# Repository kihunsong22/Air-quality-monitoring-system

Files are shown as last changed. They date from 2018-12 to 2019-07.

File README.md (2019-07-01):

# Air-quality-monitoring-system
Air quality monitoring system based on LoRa and Node.JS

<!-- ![LoRa_modules](Pictures/V2_sensor.jpg | width=400) -->
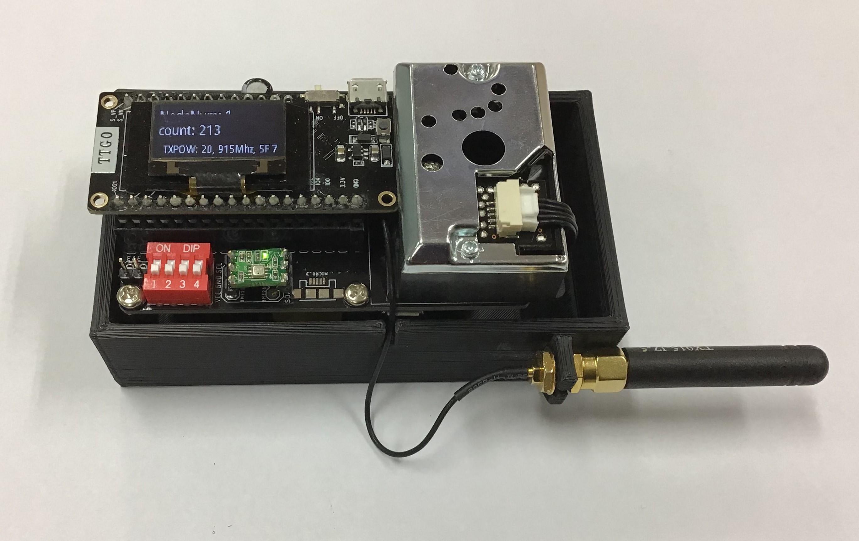
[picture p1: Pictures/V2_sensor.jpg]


LoRa Sensor Node

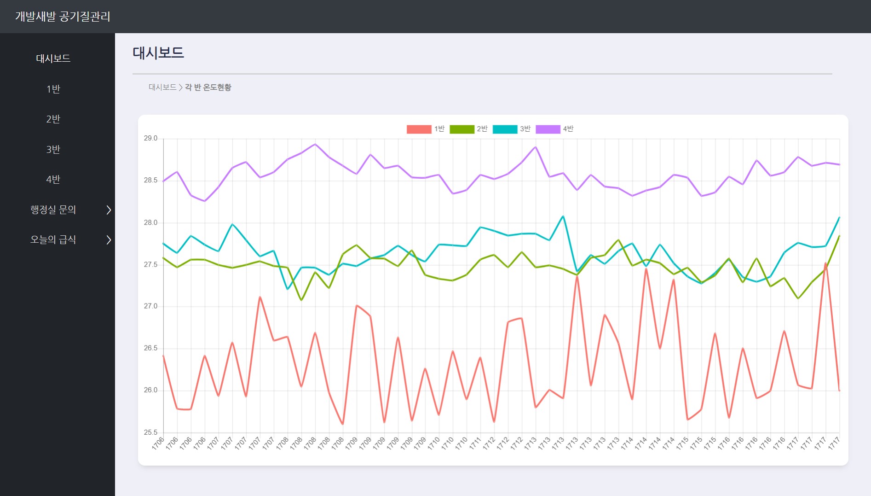
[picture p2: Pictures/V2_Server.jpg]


Node.JS Web Server

Hardware is based on TTGO-LoRa V2 board. Sensor nodes utilize BME280 and GP2y1024AU0F sensor and send it to the gateway via LoRa. Gateway will then upload the sensor data to the server via WiFi.

My system uses 4 sensor nodes and 1 gateway, but configurations can be changed

### Issues & To-Do lists
1. CLX1 pin on the ESP32 which is connected to pin 0 of the DIP switch maintains 2.7V, and prevents uploading when pulled up to 3.3V. Pin 2 of ESP32 should be changed to pin 0 of ESP32 since it's connected to the board LED
1. The PCB isn't long enough for the GP2Y10 dust sensor. And the 18650 battery blocks the hole for the sensor
1. 3.3V -> 5V boost converter is necessary since the GP2Y10 sensor utilizes 5V.
1. 3.3V and GND test pins should be moved to a different location

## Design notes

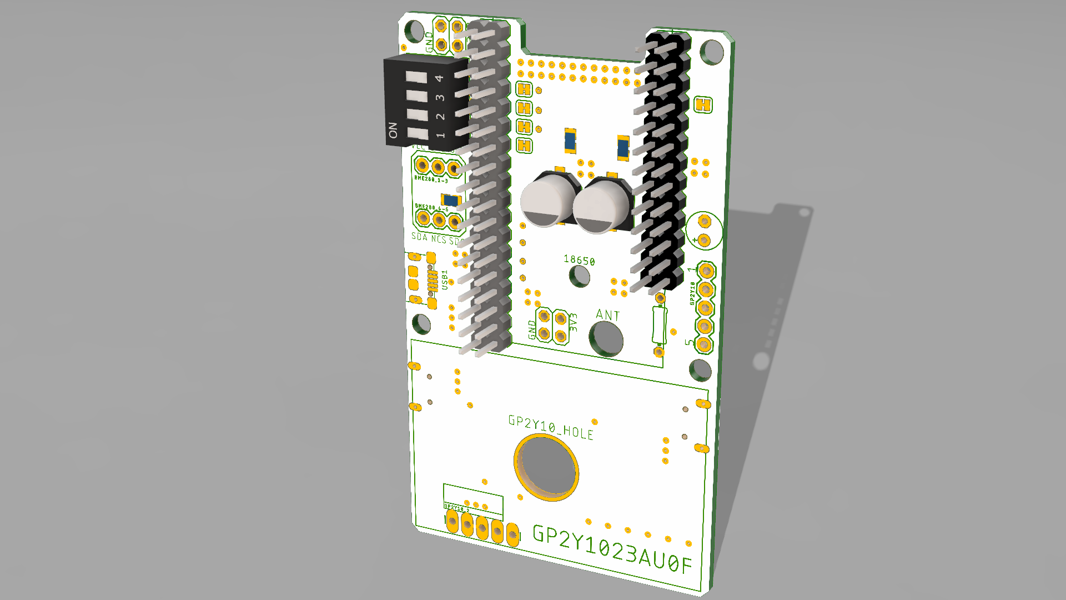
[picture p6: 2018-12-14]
V2/Pictures/PCB/PCB Rendering.png

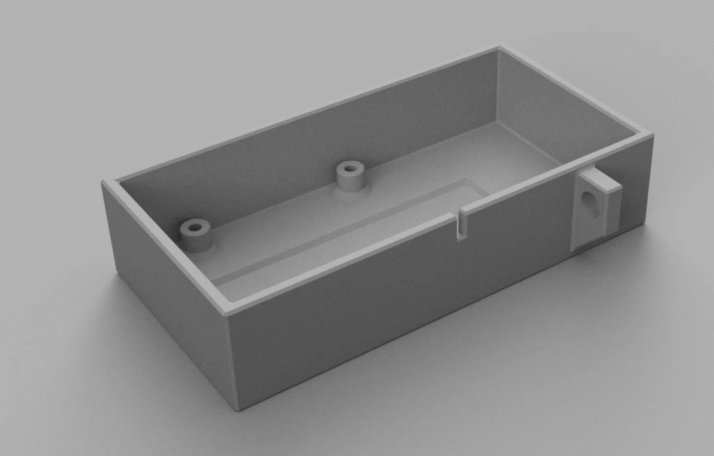
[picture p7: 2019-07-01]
Pictures/LoRa case rendering.png

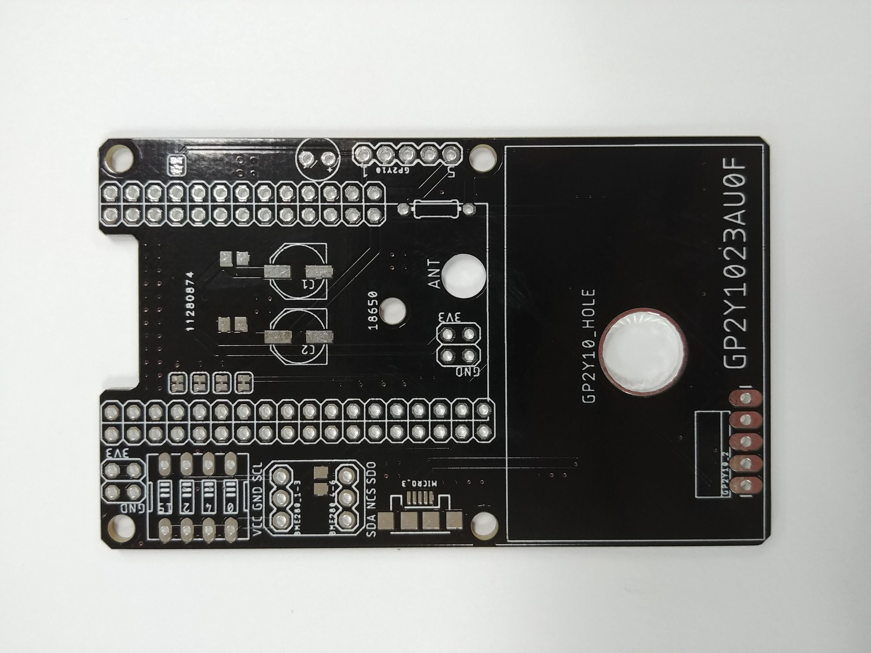
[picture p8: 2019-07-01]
V2/Pictures/PCB/PCB (2).jpg

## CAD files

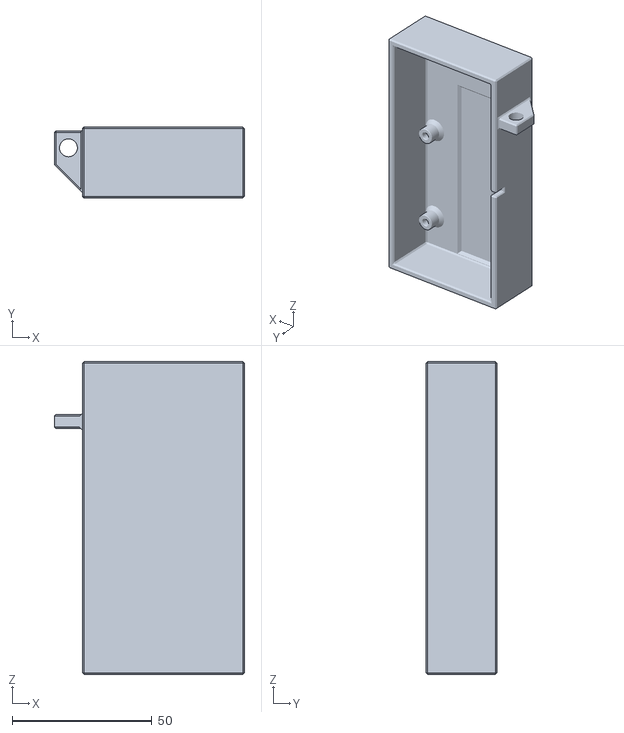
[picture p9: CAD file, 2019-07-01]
V2/3D case/lora case.stl
68.0 x 25.5 x 112.0

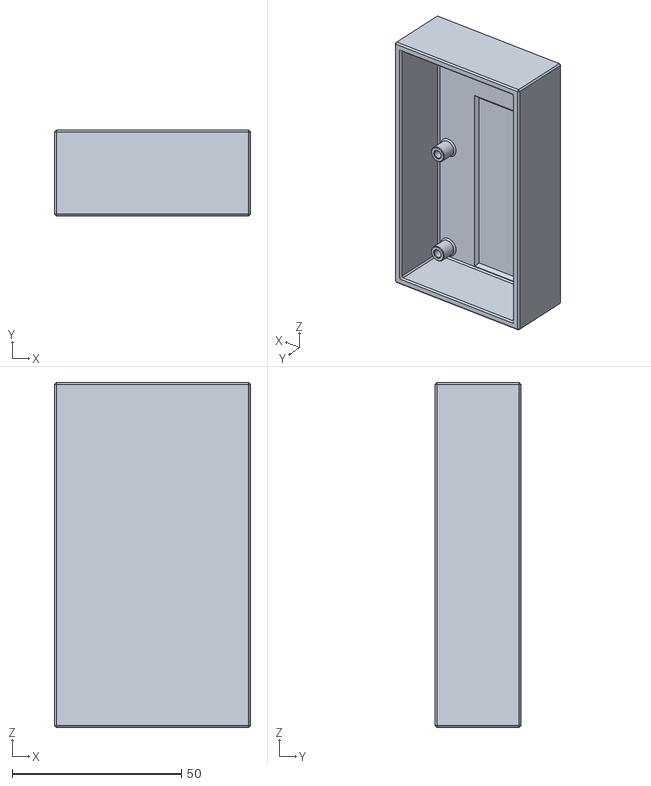
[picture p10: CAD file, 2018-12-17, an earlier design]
V1/3D case/lora case.stl
58.0 x 25.5 x 102.0

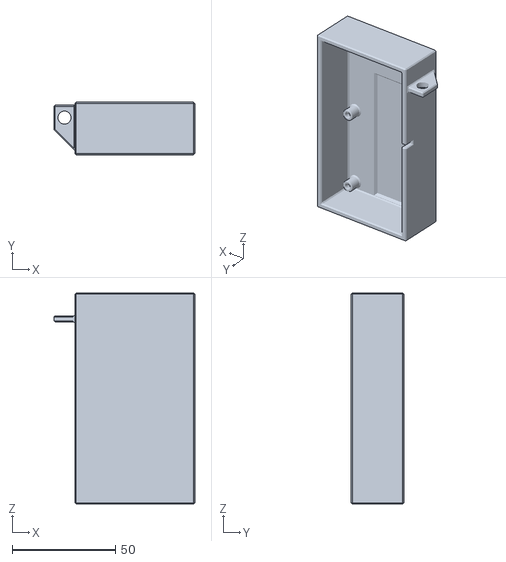
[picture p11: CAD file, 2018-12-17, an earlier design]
V1/3D case/lora case with antenna.stl
68.0 x 25.5 x 102.0

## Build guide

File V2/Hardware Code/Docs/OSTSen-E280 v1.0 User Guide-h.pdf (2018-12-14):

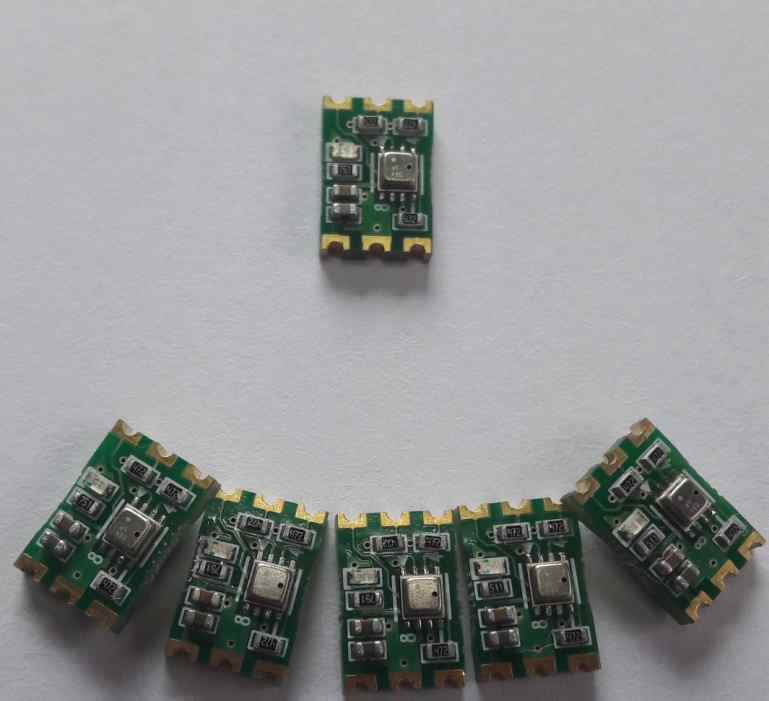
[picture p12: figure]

OSTSen-E280 v1.0 | 1 of 8 | Hara Systems Inc.

# OSTSen-E280 User Guide

## Ver 1.0

Hara Systems Inc.

OSTSen-E280 v1.0 | 2 of 8 | Hara Systems Inc.

### 1. OSTSen-E280 Overview

OSTSen-E280 is a humidity, pressure and temperature sensing module, which is based on Bosch Sensortec BME280. The BME280 is as combined digital humidity, pressure and temperature sensor based on proven sensing principles. The sensor module is housed in an extremely compact metal-lid LGA package with a footprint of only 2.5 x 2.5 mm² with a height of 0.94 mm. Its small dimensions and its low power consumption allow implementation in battery driven devices such as handsets, GPS modules or watches. The BME280 is register and performance compatible to the Bosch Sensortec BMP280 digital pressure sensor.
The BME280 achieves high performance in all application requiring humidity and pressure measurement. These emerging applications of home automation control, in- door navigation, health care as well as GPS refinement require a high accuracy and

a low TCO at the same time.
The humidity sensor provides an extremely fast respones time for fast context awareness applications and high overall accuracy over a wide temperature range. The pressure sensor is an absolute barometric pressure sensor with extremely high accuracy and resolution and drastically lower noise than the Bosch Sensortec BMP180.
The integrated temperature sensor has been optimized for lowest noise and highest resolution. Its output is used for temperature compensation of the pressure and humidity sensors and can also be used for estimation of the ambient temperature. The sensor provides both SPI and I2C interface and can be supplied using 1.71V to 3.6V for the sensor supply VDD and 1.2 to 3.6 V for the interface supply VDDIO. Measurements can be trigged by the host or performance in regular intervals. When the sensor is disabled, current consumption drops to 0.1uA.
BME280 can be operated in three power modes: sleep mode, normal mode, forced mode
In order to tailor data rate, noise, response time and current consumption to the needs of the user, a variety of oversampling modes, filter modes and data rates can be selected.

### 2. Application

- Context awareness, e.g. skin detection, room change detection
- Health monitoring/well-being
- Warning regarding dehydration or heat stroke
- Spirometry(measurement of lung volume and air flow) · Home automation control - Control heating, venting, air conditioning (HAVC) · Internet of things
- GPS enhancement · Indoor navigation
- Outdoor navigation, leisure and sports applications
- Weather forecast · Vertical velocity indication (rise/sink speed)

OSTSen-E280 v1.0 | 3 of 8 | Hara Systems Inc.

### 3. Features

### 3.1 key feature

- Package type : 2.5m x 2.5mm x 0.93mm metal lid LGA
- Digital interface : I2C (up to 3.4MHz) ad SPI(3 and 4 wire, up to 10MHz) · Supply voltage : VDD main supply voltage range : 1.71V to 3.6V

VDDIO interface voltage range : 1.2V to 3V
- Current range : 1.8uA @1Hz humidity and pressure
2.8uA @1Hz pressure and temperature
3.6uA @1Hz humidity, pressure and temperature 0.1uA in sleep mode
- Current range : -40°C ~ 85°C , 0 ~ 100 relative humidity, 300~1100hPa
- Humidity sensor and pressure sensor can be independently enabled / disabled
- Register and performance compatible to Bosch Sensortec BMP280 digital pressure sensor · RoHS compliant, halogen-free, MSL1
3.2 key parameters for humidity sensor · Response time | 1s
- Accuracu tolerance | ±3% relative humidity
- Hysteresis | ±1% relative humidity
3.2 key parameters for pressure sensor · RMS Noise | 0.2 Pa, equivalent to 1.7cm
- Offset temperature coefficient ±1.5Pa/K, equivalent to ±12.6cm at 1°C temperature change

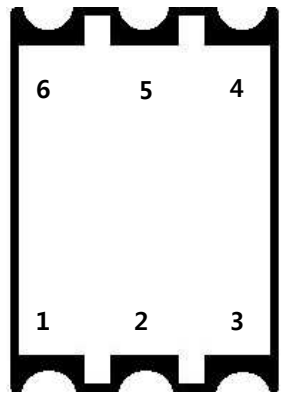
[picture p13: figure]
< TopView >

OSTSen-E280 v1.0 | 4 of 8 | Hara Systems Inc.

### 4. Application Information

### 4.1 Module Pin Out and Signal Description

Pin Number | Pin Name | Pin Description
1 | V33 | Power supply voltage (1.71V ~ 3.6V)
2 | GND | Power supply ground
3 | SCL | [I2C] Serial clock (SCL) 7bit device address : 0x76/0x77 [SPI] Serial clock (SCK)
4 | SDA | [I2C] Serial data (SDA) [SPI] Serial data (SDI)
5 | NCS | [I2C] VDDIO ( internal pull-up in OSTSen-E280 ) [SPI] Chip Select (CS)
6 | SDO | [I2C] Device address [ ‘0’: 0x76, ‘1’: 0x77 ] [SPI] Serial data output (SDO)

l BME280 I2C 7bit Device Address : 0x76 / 0x77

MSB | LSB 1 | 1 | 1 | 0 | 1 | 1 | X | R/W

< Top View >

V33 | GND | SCL

SDA
SDO NCS

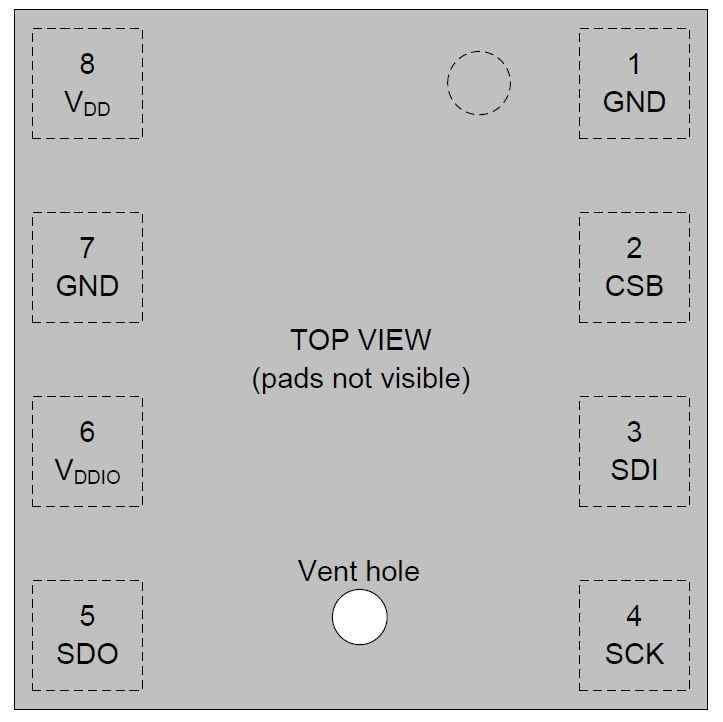
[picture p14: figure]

OSTSen-E280 v1.0 | 5 of 8 | Hara Systems Inc.

### 4.2 BME280 Pin out and Signal Description

Pin Number | Pin Name | Pin Description
1 | GND | Ground
2 | CSB | Chip select
3 | SDI | Serial data input [I2C]SDA, [SPI]SDI
4 | SCK | Serial clock input [I2C]SCL, [SPI]SCK
5 | SDO | Serial data output [I2C]address, [SPI]SDO
6 | VDDIO | Digital/Interface supply
7 | GND | Ground
8 | VDD | Power supply

< BME280 Pinout ( top view ) >

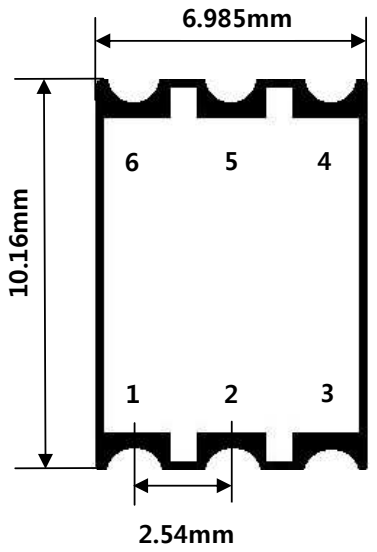
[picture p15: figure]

OSTSen-E280 v1.0 | 6 of 8 | Hara Systems Inc.

### 5. Module Dimension

< OSTSen-E280 module >

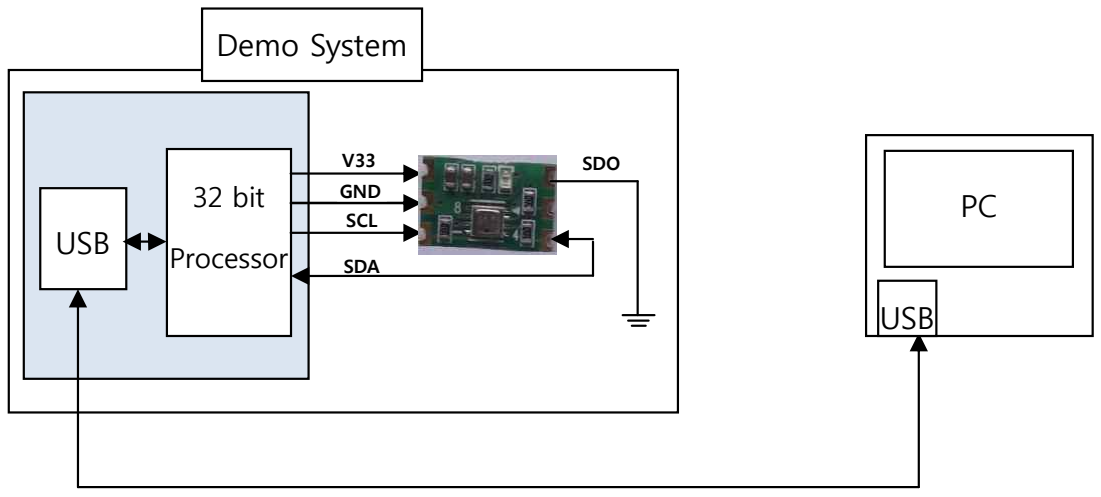
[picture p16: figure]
32 bit; Processor USB; GND; SCL; SDA; Demo System; USB; SDO
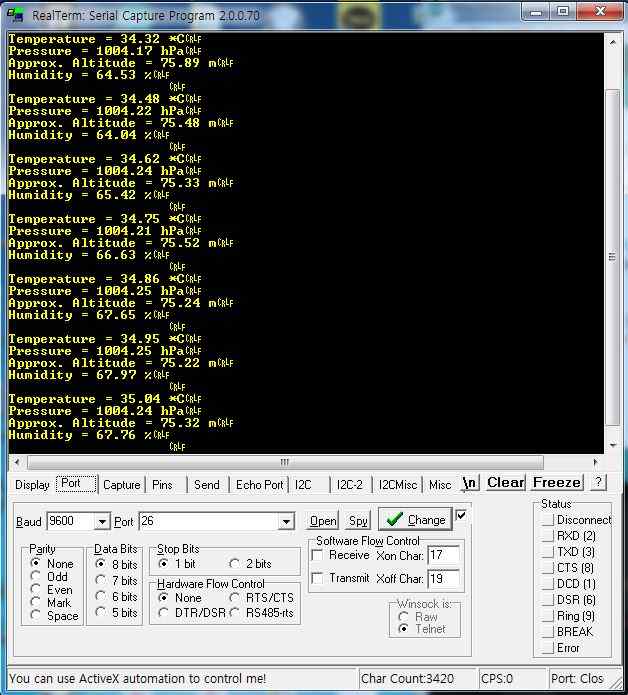
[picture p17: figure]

OSTSen-E280 v1.0 | 7 of 8 | Hara Systems Inc.

### 6. Demo System

OSTSen-E280 Data Display on PC

OSTSen-E280 v1.0 | 8 of 8 | Hara Systems Inc.

### 7. Reference

1) https://www.bosch-sensortec.com/bst/products/all_products/bme280
2) https://ae-bst.resource.bosch.com/media/_tech/media/datasheets/BST- BME280_DS001-11.pdf
3) https://github.com/adafruit/Adafruit_BME280_Library
4) https://github.com/sparkfun/SparkFun_BME280_Arduino_Library

l If you need more information or have some questions about OSTSen-E280, contact ostsen@hanmail.net.

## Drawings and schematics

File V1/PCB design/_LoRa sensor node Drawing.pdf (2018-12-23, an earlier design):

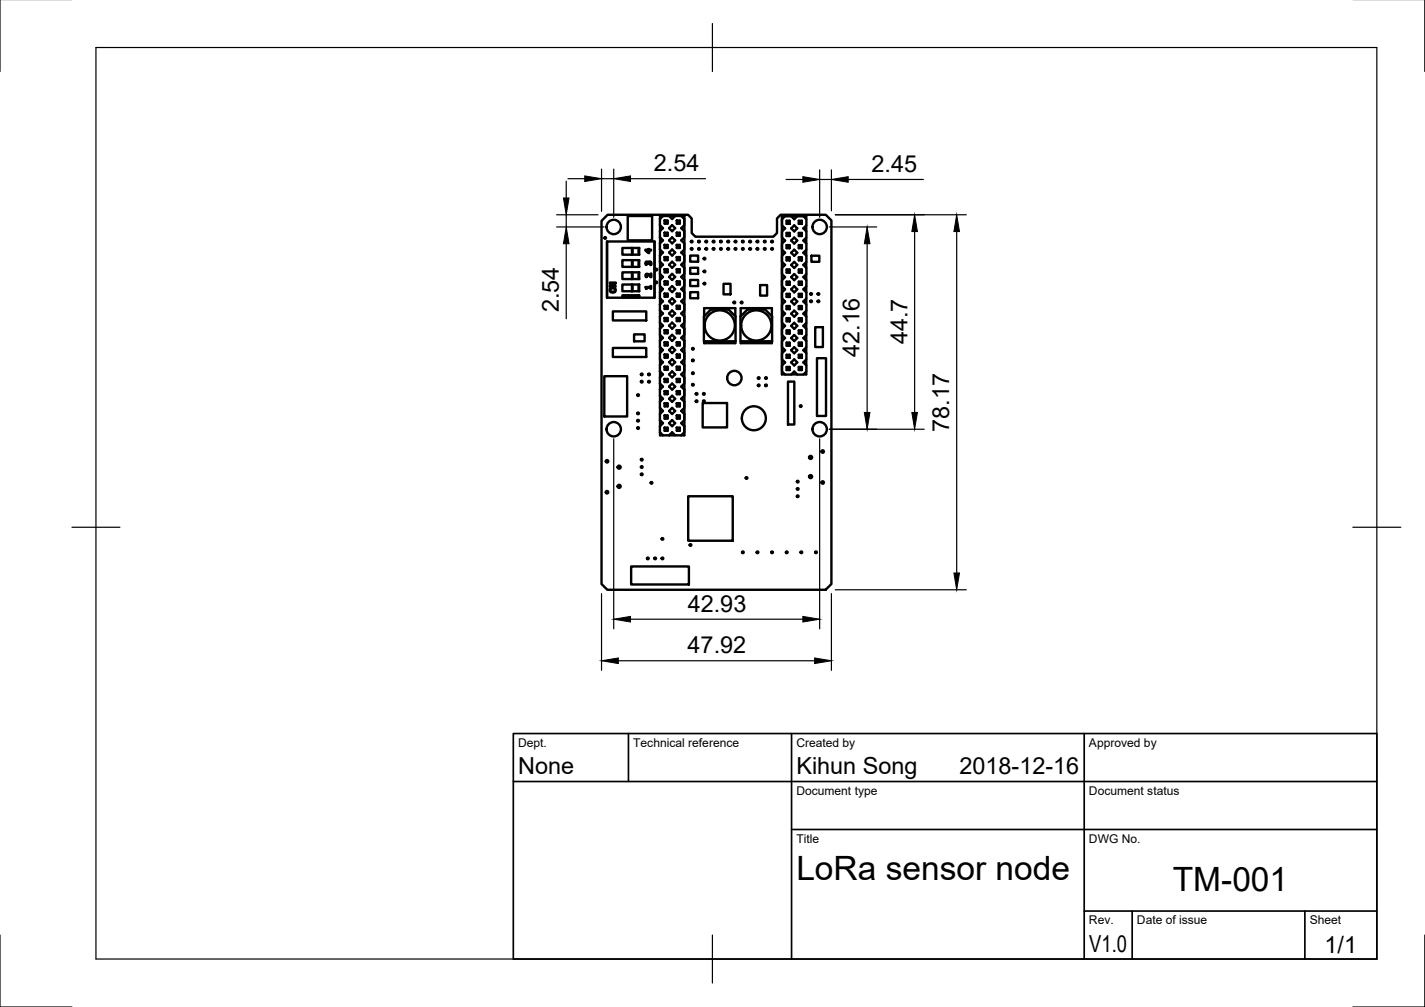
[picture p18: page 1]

Dept. None | Technical reference | Created by Kihun Song 2018-12-16 | Approved by

Document type | Document status

Title | DWG No. TM-001 LoRa sensor node

Rev. V1.0 | Date of issue | Sheet 1/1

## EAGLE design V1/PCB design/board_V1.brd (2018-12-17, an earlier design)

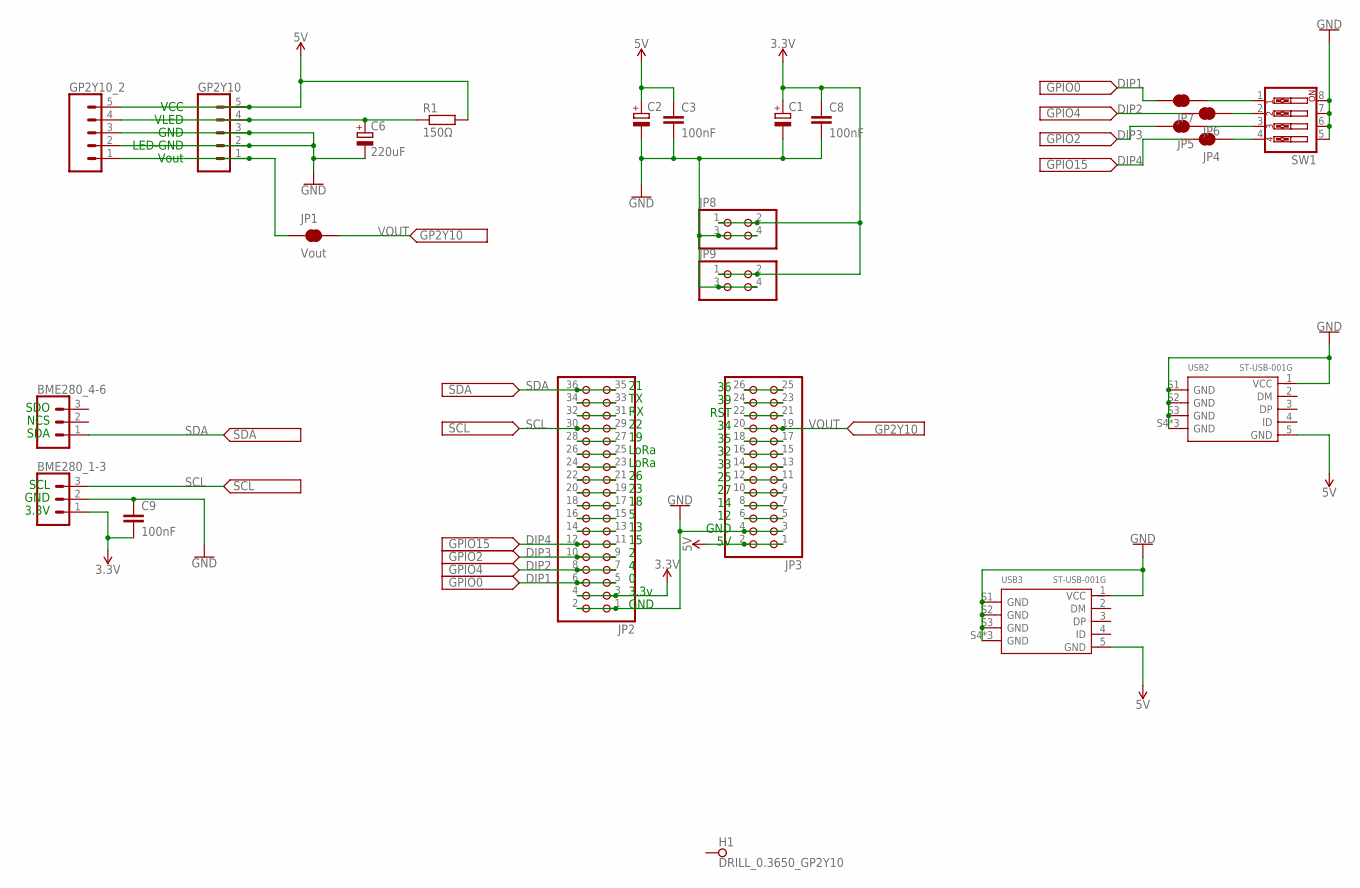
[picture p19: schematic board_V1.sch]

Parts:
BME280_1-3, BME280_4-6: CONN_03; 1X03
C1, C2: CPOL-EUD; PANASONIC_D
C3, C8, C9: 100nF; C0805
C6: 220uF; E2,5-5
GP2Y10: CONN_05; 1X05
GP2Y10_2: CONN_05PTH_LONGPADS; 1X05_LONGPADS
H1: DRILL_0.3650_GP2Y10; PAD_0.3650
JP1: Vout; SMT-JUMPER_2_NC_TRACE_SILK
JP2: PINHD-2X18; 2X18
JP3: PINHD-2X13; 2X13
JP4, JP5, JP6, JP7: JUMPER-SMT_2_NC_TRACE_SILK; SMT-JUMPER_2_NC_TRACE_SILK
JP8, JP9: PINHD-2X2/OCT; 2X02
R1: 150Ω; 0204/7
SW1: SW_DIP-4; EDG-04
USB2, USB3: ST-USB-001G; MICRO-USB5+4P-SMD-0.65-B

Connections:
3.3V: BME280_1-3.1, C1.+, C8.1, C9.2, JP2.3, JP2.4, JP8.1, JP8.2, JP9.1, JP9.2
5V: C2.+, C3.1, GP2Y10.5, GP2Y10_2.5, JP3.1, JP3.2, R1.2, USB2.5 (GND), USB3.5 (GND)
DIP1: JP2.5, JP2.6, JP7.2
DIP2: JP2.7, JP2.8, JP6.2
DIP3: JP2.9, JP2.10, JP5.2
DIP4: JP2.11, JP2.12, JP4.2
GND: BME280_1-3.2, C1.-, C2.-, C3.2, C6.-, C8.2, C9.1, GP2Y10.2, GP2Y10.3, GP2Y10_2.2, GP2Y10_2.3, JP2.1, JP2.2, JP3.3, JP3.4, JP8.3, JP8.4, JP9.3, JP9.4, SW1.5, SW1.6, SW1.7, SW1.8, USB2.1 (VCC), USB2.S1 (GND), USB2.S2 (GND), USB2.S3 (GND), USB2.S4 (GND), USB2.S5 (GND), USB2.S6 (GND), USB3.1 (VCC), USB3.S1 (GND), USB3.S2 (GND), USB3.S3 (GND), USB3.S4 (GND), USB3.S5 (GND), USB3.S6 (GND)
unnamed: JP7.1, SW1.1
unnamed: JP6.1, SW1.2
unnamed: JP2.33, JP2.34
unnamed: JP2.31, JP2.32
unnamed: JP2.27, JP2.28
unnamed: JP2.25, JP2.26
unnamed: JP3.25, JP3.26
unnamed: JP3.23, JP3.24
unnamed: JP3.21, JP3.22
unnamed: JP3.17, JP3.18
unnamed: JP5.1, SW1.3
unnamed: JP3.15, JP3.16
unnamed: JP3.13, JP3.14
unnamed: JP3.11, JP3.12
unnamed: JP3.9, JP3.10
unnamed: JP3.7, JP3.8
unnamed: JP3.5, JP3.6
unnamed: JP4.1, SW1.4
unnamed: JP2.13, JP2.14
unnamed: JP2.15, JP2.16
unnamed: JP2.17, JP2.18
unnamed: JP2.19, JP2.20
unnamed: JP2.21, JP2.22
unnamed: JP2.23, JP2.24
SCL: BME280_1-3.3, JP2.29, JP2.30
SDA: BME280_4-6.1, JP2.35, JP2.36
VLED: C6.+, GP2Y10.4, GP2Y10_2.4, R1.1
VOUT: JP1.2, JP3.19, JP3.20
VOUT_1: GP2Y10.1, GP2Y10_2.1, JP1.1

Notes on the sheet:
Vout
LED-GND
GND
VLED
VCC
LoRa
3.3v
RST
3.3V
SCL
SDA
NCS
SDO

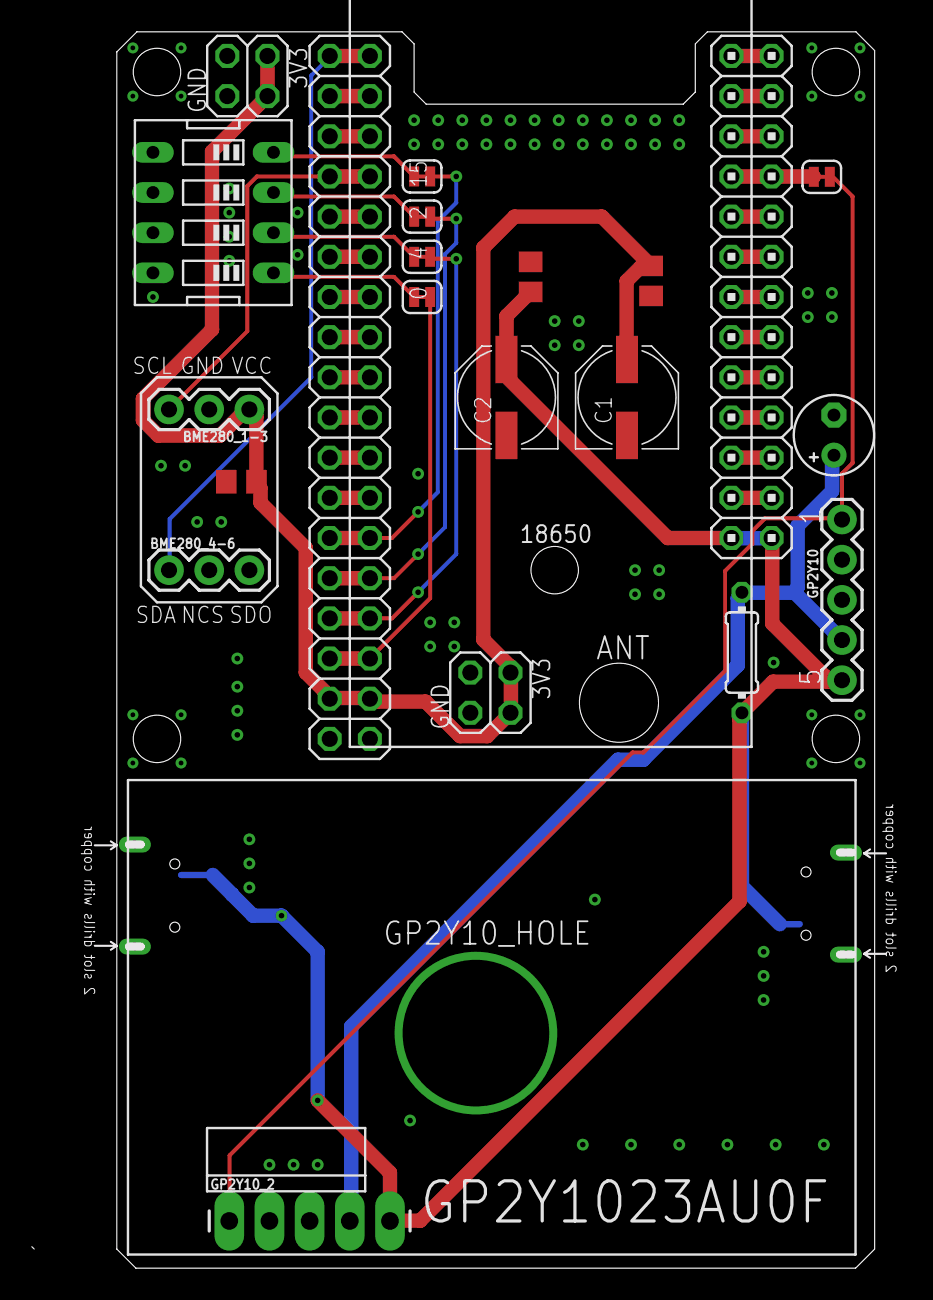
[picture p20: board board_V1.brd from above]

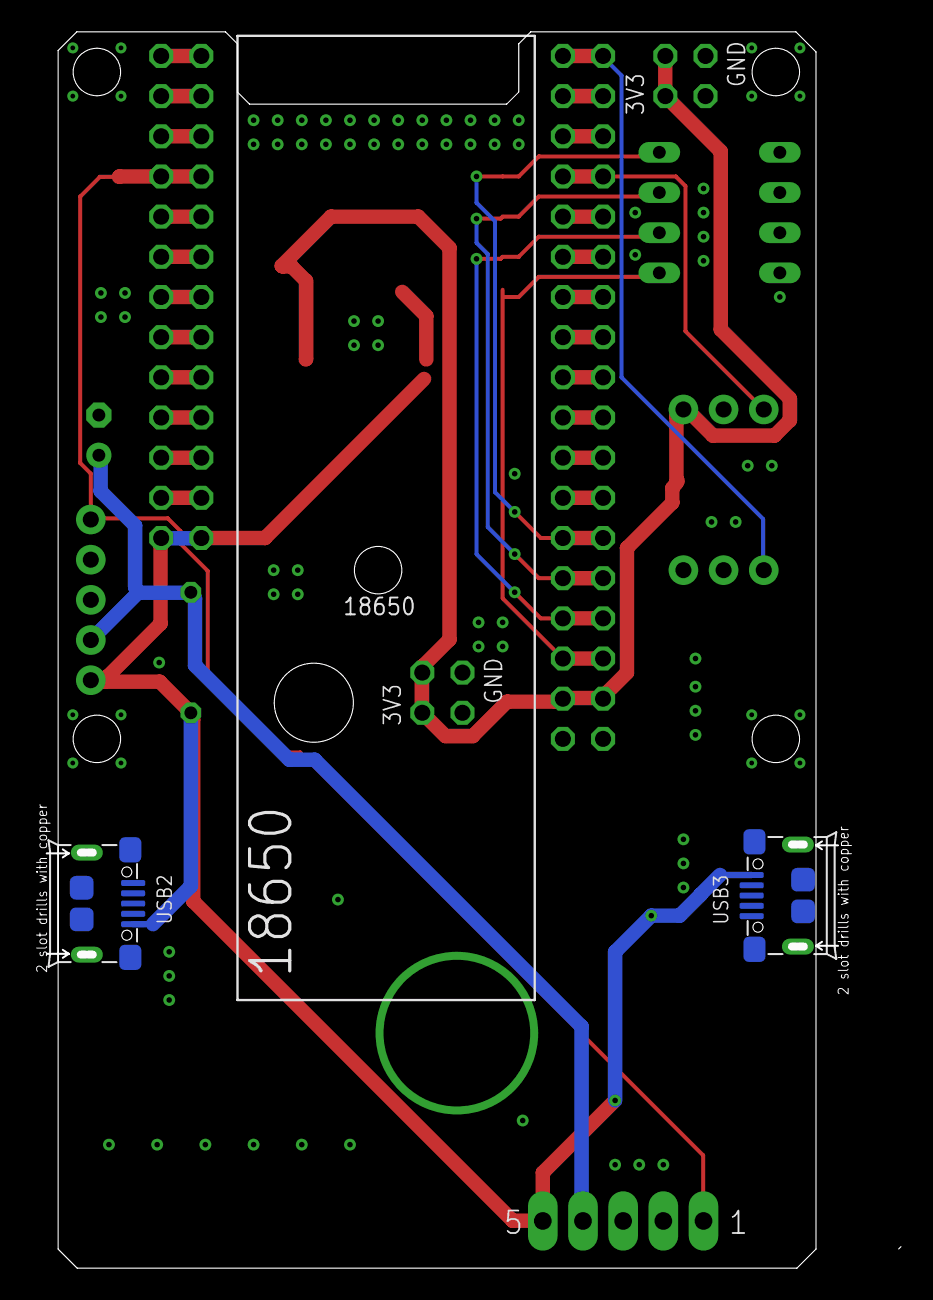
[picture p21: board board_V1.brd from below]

Board: 2 copper layers, 47.9 x 78.2 mm, 24 parts (2 on the bottom side), 36 nets.

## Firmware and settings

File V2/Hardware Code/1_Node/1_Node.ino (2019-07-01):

#include <Arduino.h>
#include <SPI.h>
#include <LoRa.h>
#include <Wire.h>
#include <BME280I2C.h>  // https://github.com/finitespace/BME280
#include "SSD1306.h"
#include "fonts.h"  //Open_Sans_Hebrew_Condensed_14, Open_Sans_Hebrew_Condensed_18, Open_Sans_Hebrew_Condensed_24

#define SCK     5    // GPIO5  -- SX1278's SCK
#define MISO    19   // GPIO19 -- SX1278's MISO
#define MOSI    27   // GPIO27 -- SX1278's MOSI
#define SS      18   // GPIO18 -- SX1278's CS
#define RST     14   // GPIO14 -- SX1278's RESET
#define DI0     26   // GPIO26 -- SX1278's IRQ(Interrupt Request)

#define BAND  915E6  // 433E6, 868E6, 915E6
#define TXPOW 20 // 2~20 -> PA_OUTPUT_RF0_PIN, 0~14-> PA_OUTPUT_BOOST_PIN
#define SF 7 // Spreading Factor: 6~12, default 7
#define SBW 125E3 // Signal Bandwidth: 7.83E, 10.4E3, 15.6E3, 20.8E3, 41.7E3, 62.5E3, 125.E3, 250E3, default 125E3
#define CR 8 // Coding Rate: 5~8, default 5

#define DEBUG 0  // 0: normal state, 1: radom sensor values
const uint8_t GP2Y10 = 34;
const uint8_t dipPin1 = 15;
const uint8_t dipPin2 = 2;  // LED pin - should be replaced
const uint8_t dipPin3 = 4;
const uint8_t dipPin4 = 0;  // CLX1 pin - should be replaced

BME280I2C::Settings settings(
	BME280::OSR_X8,  // temp oversampling
	BME280::OSR_X8,  // humidity oversampling
	BME280::OSR_X8,  // pressure oversampling
	BME280::Mode_Forced,  // operation mode
	BME280::StandbyTime_1000ms,  // standby time
	BME280::Filter_Off,  // filter
	// BME280::Filter_2,  // filter
	BME280::SpiEnable_False,  // spi interface
	BME280I2C::I2CAddr_0x76 // I2C address. I2C specific.
);
BME280::TempUnit tempUnit(BME280::TempUnit_Celsius);
BME280::PresUnit presUnit(BME280::PresUnit_Pa);

SSD1306 display(0x3c, 21, 22);
BME280I2C bme(settings);

void printInfo();


uint8_t dip1, dip2, dip3, dip4, NodeNum = 0;
uint32_t packCount = 0;

void setup() {
	Serial.begin(115200);
	Serial.println("\n\nDevice - LoRa Sensor Node");
	if(DEBUG == 1){
		Serial.println("#########################################");
		Serial.println("#  Debug mode on - random sensor values  #");
		Serial.println("#########################################");
	}

	Wire.begin();

  pinMode(GP2Y10, INPUT);
	pinMode(16, OUTPUT);  // OLED reset pin
	digitalWrite(16, LOW);    // set GPIO16 low to reset OLED
	delay(50);
	digitalWrite(16, HIGH); // while OLED is running, must set GPIO16 in high

	pinMode(dipPin1, INPUT);  // CLX1 pin, seems to have special function - 2.72V on LOW
	pinMode(dipPin2, INPUT_PULLDOWN);  // also works as LED pin
	pinMode(dipPin3, INPUT_PULLDOWN);  //all connected to 3V3
	pinMode(dipPin4, INPUT_PULLDOWN);

	dip1 = digitalRead(dipPin1);  // read node number from external DIP switch
	dip2 = digitalRead(dipPin2);
	dip3 = digitalRead(dipPin3);
	dip4 = analogRead(dipPin4)>4000?1:0;  // designated pin CLX1: seems to have special function, disconnect before upload
	NodeNum = dip1 + dip2*2 + dip3*4 + dip4*8 + 1;

	display.init();
	display.flipScreenVertically();
	display.clear();
	display.setFont(Open_Sans_Hebrew_Condensed_24);
	display.setTextAlignment(TEXT_ALIGN_LEFT);
	display.drawString(0, 0, "LoRa Sensor");
	display.setTextAlignment(TEXT_ALIGN_LEFT);
	printInfo();
	display.display();

	SPI.begin(SCK,MISO,MOSI,SS);
	LoRa.setPins(SS,RST,DI0);
	LoRa.setTxPower(TXPOW);
	LoRa.setSpreadingFactor(SF);
	LoRa.setSignalBandwidth(SBW);
	LoRa.setCodingRate4(CR);
	if (LoRa.begin(BAND)) {
		Serial.println("LoRa Initialized.");
	}else{
		Serial.println("LoRa failed to start.");
		while (1){
			delay(1000);
		}
	}
	LoRa.receive();
	
	if(DEBUG == 0){
		uint8_t bmeInitCount = 0;
		while(!bme.begin()){
			Serial.println("BEM280 Not Found.");
			delay(1000);

			bmeInitCount++;
			if(bmeInitCount>4) {	break;	}
		}
		switch(bme.chipModel()){
			case BME280::ChipModel_BME280:
				Serial.println("BME280 Initialized.");
				break;
			case BME280::ChipModel_BMP280:
				Serial.println("BMP280 Initialized. No Humidity available.");
				break;
			default:
				Serial.println("BME280 Initialization FAILED!");
		}
	}

	Serial.print("\nDIP1: "); Serial.println(dip1);
	Serial.print("DIP2: "); Serial.println(dip2);
	Serial.print("DIP3: "); Serial.println(dip3);
	Serial.print("DIP4: "); Serial.println(dip4);
	Serial.print("\nNodeNum:"); Serial.println(NodeNum);

  Serial.println("Init complete\n");
	delay(250);
}

String packet = "";
float bmetemp(NAN), bmehum(NAN), bmepres(NAN);
float dust = 0.0;

void loop() {
	dip1 = digitalRead(dipPin1);  // check for update on DIP switch
	dip2 = digitalRead(dipPin2);
	dip3 = digitalRead(dipPin3);
	dip4 = analogRead(dipPin4)>4000?1:0;  // designated pin CLX1: seems to have special function, pull low before upload
	NodeNum = dip1 + dip2*2 + dip3*4 + dip4*8 + 1;

	if(DEBUG == 0){
  	bme.read(bmepres, bmetemp, bmehum, tempUnit, presUnit);
		Serial.print("\nNodeNum:"); Serial.println(NodeNum);
		Serial.print("Temp: "); Serial.print(bmetemp); Serial.print("°"+ String(tempUnit==BME280::TempUnit_Celsius?"C":"F"));
		Serial.print("    Humidity: "); Serial.print(bmehum); Serial.print("% RH");
		Serial.print("    Pressure: "); Serial.print(bmepres); Serial.println("Pa");

		// printBME280Data(&Serial);
		dust = pulse2ugm3(pulseIn(GP2Y10, LOW, 20000));
		dust = dust<0?0:dust;
  	Serial.print("Dust: "); Serial.print(dust, 3); Serial.println(" ug/m3");

		Serial.flush();
	}else{
		bmepres = 1010000 + random(0, 8000000)/100.0;  // 101000 ~ 109000
		bmetemp = 22.0 + random(0, 1000)/100.0;  // 22~32
		bmehum = 25.0 + random(0, 5000)/100.0;  // 25~75
		Serial.print("Temp: "); Serial.print(bmetemp); Serial.print("°"+ String(tempUnit==BME280::TempUnit_Celsius?"C":"F"));
		Serial.print("    Humidity: "); Serial.print(bmehum); Serial.print("% RH");
		Serial.print("    Pressure: "); Serial.print(bmepres); Serial.println("Pa");

		dust = 10.0 + random(0, 1000)/100.0; // 10~20
  	Serial.print("Dust: "); Serial.print(dust, 3); Serial.println(" ug/m3");
		Serial.flush();
	}

	packet = "";  // NodeNum, dust, temp, hum, pres
	packet.concat("$");
	packet.concat(String(NodeNum));
	packet.concat("#");
	packet.concat(String(dust, 2));
	packet.concat("#");
	packet.concat(bmetemp);
	packet.concat("#");
	packet.concat(bmehum);
	packet.concat("#");
	packet.concat(bmepres);
	packet.concat("$  ");

	Serial.print("LoRa packet: "); Serial.println(packet); Serial.println("");

	LoRa.beginPacket();
	LoRa.print(packet);
	LoRa.endPacket();

	packCount++;

	display.clear();
	display.setFont(Open_Sans_Hebrew_Condensed_18);
	display.setTextAlignment(TEXT_ALIGN_LEFT);
	display.drawString(0, 0, "NodeNum: " + String(NodeNum));
	display.drawString(0, 20, "count: " + String(packCount));
	printInfo();
	display.display();
	
	Serial.flush();
	uint16_t delayt = 5000 + random(0, 1000);
	delay(delayt);
}


float pulse2ugm3(uint16_t pulse){
  float value = (pulse-1400)/14.0;
  if(value > 300){
    value = 0;
  }
  return value;
}

void printBME280Data(Stream* client){
  bme.read(bmepres, bmetemp, bmehum, tempUnit, presUnit);

  client->print("Temp: ");
  client->print(bmetemp);
  client->print("°"+ String(tempUnit == BME280::TempUnit_Celsius ? 'C' :'F'));
  client->print("    Humidity: ");
  client->print(bmehum);
  client->print("% RH");
  client->print("    Pressure: ");
  client->print(bmepres);
  client->println("Pa");
}

void printInfo(){
	display.setFont(Open_Sans_Hebrew_Condensed_14);
	display.setTextAlignment(TEXT_ALIGN_RIGHT);

	switch( String(BAND).substring(0, 3).toInt() ) {
		case 433:
			display.drawString(128, 48, "TXPOW: " + String(TXPOW) + ", 433Mhz, SF " + String(SF));
			break;

		case 868:
			display.drawString(128, 48, "TXPOW: " + String(TXPOW) + ", 868Mhz, SF " + String(SF));
			break;

		case 915:
			display.drawString(128, 48, "TXPOW: " + String(TXPOW) + ", 915Mhz, SF " + String(SF));
			break;
		
		default:
			break;
	}
}

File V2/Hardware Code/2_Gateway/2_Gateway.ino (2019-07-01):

#include <Arduino.h>
#include <SPI.h>
#include <LoRa.h>
#include <WiFi.h>
#include <WiFiMulti.h>
#include <HTTPClient.h>
#include <Wire.h>
#include "SSD1306.h"
#include "fonts.h"  //Open_Sans_Hebrew_Condensed_14, Open_Sans_Hebrew_Condensed_18, Open_Sans_Hebrew_Condensed_24

#define SCK     5    // GPIO5  -- SX1278's SCK
#define MISO    19   // GPIO19 -- SX1278's MISO
#define MOSI    27   // GPIO27 -- SX1278's MOSI
#define SS      18   // GPIO18 -- SX1278's CS
#define RST     14   // GPIO14 -- SX1278's RESET
#define DI0     26   // GPIO26 -- SX1278's IRQ(Interrupt Request)

#define BAND  915E6  // 433E6, 868E6, 915E6
#define TXPOW 20 // 2~20 -> PA_OUTPUT_RF0_PIN, 0~14-> PA_OUTPUT_BOOST_PIN
#define SF 7 // Spreading Factor: 6~12, default 7
#define SBW 125E3 // Signal Bandwidth: 7.83E, 10.4E3, 15.6E3, 20.8E3, 41.7E3, 62.5E3, 125.E3, 250E3, default 125E3
#define CR 8 // Coding Rate: 5~8, default 5


WiFiMulti WiFiMulti;
HTTPClient http;
SSD1306 display(0x3c, 21, 22);

void printInfo();
int filter_okay(float val1, float val2, float newVal);


void setup() {
	Serial.begin(115200);
	Serial.println("\n\nDevice - LoRa Gateway");

	pinMode(16, OUTPUT);  // OLED reset pin
	pinMode(2, OUTPUT);  //LED
	digitalWrite(16, LOW);    // set GPIO16 low to reset OLED
	delay(50);
	digitalWrite(16, HIGH); // while OLED is running, must set GPIO16 in high

	display.init();
	display.flipScreenVertically();
	display.clear();
	display.setFont(Open_Sans_Hebrew_Condensed_24);
	display.setTextAlignment(TEXT_ALIGN_LEFT);
	display.drawString(0, 0, "LoRa Gateway");
	printInfo();
	display.display();

	WiFi.mode(WIFI_STA);
	WiFiMulti.addAP("DimiFi 2G1", "newdimigo");
	WiFiMulti.addAP("DimiFi 2G2", "newdimigo");
	WiFiMulti.addAP("DimiFi-2G", "newdimigo");
	WiFiMulti.addAP("DimiFi_2G", "newdimigo");
	WiFiMulti.addAP("DimiFi-1", "newdimigo");
	Serial.print("Establishing WiFI connection");
	uint16_t wifiCount = 0;
	while(WiFiMulti.run() != WL_CONNECTED) {
		// ESP.wdtFeed();  // uneccesary for ESP32
		Serial.print(".");
		delay(250);
		wifiCount++;
		if(wifiCount>60){
			ESP.restart();  // WiFi connection takes too long
			return;
		}
	}
	Serial.print("\nWiFi Connected: ");
	Serial.println(WiFi.SSID());
	Serial.print("IP address: ");
	Serial.println(WiFi.localIP());
	WiFi.printDiag(Serial);
	Serial.println();

	display.clear();
	display.setFont(Open_Sans_Hebrew_Condensed_24);
	display.setTextAlignment(TEXT_ALIGN_LEFT);
	display.drawString(0, 0, "LoRa Gateway");
	display.setFont(Open_Sans_Hebrew_Condensed_18);
	display.setTextAlignment(TEXT_ALIGN_LEFT);
	display.drawString(0, 26, "WiFi connected");
	printInfo();
	display.display();

	SPI.begin(SCK,MISO,MOSI,SS);
	LoRa.setPins(SS,RST,DI0);
	LoRa.setTxPower(TXPOW);
	LoRa.setSpreadingFactor(SF);
	LoRa.setSignalBandwidth(SBW);
	LoRa.setCodingRate4(CR);
	if (LoRa.begin(BAND)) {
		Serial.println("LoRa Initialized");
	}else{
		Serial.println("LoRa failed to start");
		while (1){
			delay(1000);
		}
	}
	LoRa.receive();

  Serial.println("Init complete\n");
	delay(200);
}


String packet = "";
int packetSize = 0;
String pac_history="";

uint32_t count_packnum = 0;
uint32_t count_packnum_a[6] = {0};
uint8_t pac_NodeNum = 0, pac_okay = 1;
float pac_dust, pac_temp, pac_hum, pac_pres = 0;

float filt_dust[6][2] = {0.0};
float filt_temp[6][2] = {0.0};
float filt_hum[6][2] = {0.0};
float filt_pres[6][2] = {0.0};

float httpData[6][4] = {0.0};

void loop() {
	packetSize = LoRa.parsePacket();
	if (packetSize){  // if(non-zero) -> true
		Serial.println("\n\n=====");

		packet ="";
		for (int i = 0; i < packetSize; i++){
			packet.concat((char) LoRa.read());
		}

		packet.trim();

		Serial.print("count_packnum: ");  Serial.println(count_packnum);
		Serial.print("Packet: ");  Serial.println(packet);
		Serial.print("RSSI: ");  Serial.println(String(LoRa.packetRssi(), DEC));

		if(packet.startsWith("$") && packet.endsWith("$")){
			pac_okay = 1;

			String data="";
			packet.replace("$", "");
			data = packet.substring(0, packet.indexOf("#"));
			pac_NodeNum = data.toInt();
			packet = packet.substring(packet.indexOf("#")+1);
			data = packet.substring(0, packet.indexOf("#"));
			pac_dust = data.toFloat();
			packet = packet.substring(packet.indexOf("#")+1);
			data = packet.substring(0, packet.indexOf("#"));
			pac_temp = data.toFloat();
			packet = packet.substring(packet.indexOf("#")+1);
			data = packet.substring(0, packet.indexOf("#"));
			pac_hum = data.toFloat();
			packet = packet.substring(packet.indexOf("#")+1);
			data = packet.substring(0, packet.indexOf("#"));
			pac_pres = data.toFloat();
			// data before filtering
			Serial.print("pac_NodeNum: "); Serial.println(pac_NodeNum);
			Serial.print("pac_dust: "); Serial.print(pac_dust); Serial.println("ug/m3");
			Serial.print("pac_temperature: "); Serial.print(pac_temp); Serial.println("°C");
			Serial.print("pac_humidity: "); Serial.print(pac_hum); Serial.println("% RH");
			Serial.print("pac_pressure: "); Serial.print(pac_pres); Serial.println("Pa");
			
			// data filtering
			if(pac_NodeNum<0 || pac_NodeNum>16 || pac_dust<0 || pac_temp<=0 || pac_hum<=0 || pac_pres<=0){
				Serial.println("!!!!! abnormal packet data - dropping !!!!!");
				pac_okay=0;
			}

			count_packnum_a[pac_NodeNum-1]++;

			if(count_packnum>3 && count_packnum_a[pac_NodeNum-1]>3 && pac_okay == 1){
				if(filter_okay(filt_temp[pac_NodeNum-1][0], filt_temp[pac_NodeNum-1][1], pac_temp)!=0 ) {  pac_okay = 0; Serial.println("INVALID temp, FILTER_OKAY!=0");  }
				if(filter_okay(filt_hum[pac_NodeNum-1][0], filt_hum[pac_NodeNum-1][1], pac_hum)!=0 ) {  pac_okay = 0; Serial.println("INVALID hum, FILTER_OKAY!=0");  }
				if(filter_okay(filt_pres[pac_NodeNum-1][0], filt_pres[pac_NodeNum-1][1], pac_pres)!=0 ) {  pac_okay = 0; Serial.println("INVALID pres, FILTER_OKAY!=0");  }
			}

			if(pac_okay == 1){
				filt_dust[pac_NodeNum-1][0] = filt_dust[pac_NodeNum-1][1];
				filt_dust[pac_NodeNum-1][1] = pac_dust;
				filt_temp[pac_NodeNum-1][0] = filt_temp[pac_NodeNum-1][1];
				filt_temp[pac_NodeNum-1][1] = pac_temp;
				filt_hum[pac_NodeNum-1][0] = filt_hum[pac_NodeNum-1][1];
				filt_hum[pac_NodeNum-1][1] = pac_hum;
				filt_pres[pac_NodeNum-1][0] = filt_pres[pac_NodeNum-1][1];
				filt_pres[pac_NodeNum-1][1] = pac_pres;
				count_packnum ++;

				String temp = "";
				temp = pac_NodeNum;
				temp.concat(pac_history);
				pac_history = temp;

				if(pac_history.length()>16) {  pac_history = pac_history.substring(0, 16);  }
				Serial.print("pac_history: "); Serial.println(pac_history);
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

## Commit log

2018-12-15 fixed GP2Y10, DIP switch issues
    [1_Node.ino, 2_Gateway.ino]
2018-12-17 PCB issues update, pics cleanup
    [board.brd, board.sch]
2018-12-17 3D model, PCB rendering
    [lora case with antenna.stl, lora case.stl]
2018-12-18 abnormal data filtering - needs additional testing
2019-07-01 V2 hardware update
    [board.brd, board.sch, lora case with antenna.stl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]
2019-08-22 changed file names
    [board_V1.brd, board_V1.sch, board_V2.brd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]

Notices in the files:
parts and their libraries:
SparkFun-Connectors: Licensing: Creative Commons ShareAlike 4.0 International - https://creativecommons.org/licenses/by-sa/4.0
